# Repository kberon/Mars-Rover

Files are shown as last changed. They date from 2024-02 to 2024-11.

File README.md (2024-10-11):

Repo for parts for the MIL Rover

Old Rover CAD Screenshot

contact: adammcaleer@ufl.edu

## Project Architecture
Iamge overview

### Finished tasks
Firmware has somewhat shifted away from a build system using wiringPI as a HAL for c++ - have moved towards a build system for assembly and C for performance. <br>
The basics of the drivers for PWM are done under the c_drivers directory, and drivers for an IMU and BME280 are available under the main branch now.<br>
We have now also added configurations for sonar in the form of a kernel interrupt - this being done once again in hopes of better performance<br>
<br>
Our high level software team has finished configuring ROS for our external computer nodes, and have dived into the details of ROS through toturials.<br>
<br>
Additionally, the team has dived into the battery monitor board design, and details of the future voltage dividing procedure.<br>
<br>
The team has also spent a great deal of time researching and buying parts. Included in the documentation directory are details on that procedure, especailly for the motor selection<br>
<br>
We encourage you to explore the repo and read the subdirectory README's and the different available documentation

## Bugs
Firmware bugs are as follows: PWM through DMA drivers needs to become a persistant object to capture memory leaks - otherwise causes issues when run multiple times<br>
Our sonar modules work independently, but need some kind of daisychaning or internal delays to prevent interference with one another.

## Set up to run:
1. Load the gpio_interface module for PWM
```
cd /Mars-Rover/firmware/kernel_modules/
sudo insmod gpio_interface.ko
```

## Installation:
1. Clone our repo
```
git clone https://github.com/kberon/Mars-Rover.git
```
2. Instantiate the kernel modules on start up
```
sudo nano /etc/systemd/system/load_custom_modules.service
```
In that file write:
```
[Unit]
Description=Load Custom Sonar Kernel Modules
After=network.target

[Service]
Type=oneshot
ExecStart=/sbin/insmod /home/raspberry/Mars-Rover/firmware/sonar_1/sonar_1.ko
ExecStart=/sbin/insmod /home/raspberry/Mars-Rover/firmware/sonar_2/sonar_2.ko
ExecStart=/sbin/insmod /home/raspberry/Mars-Rover/firmware/sonar_3/sonar_3.ko
RemainAfterExit=yes

[Install]
WantedBy=multi-user.target
```
Save the file and run the following commands:
```
sudo systemctl daemon-reload
sudo systemctl enable load_custom_modules.service
```

3. For the sensor setup, we will need to install the WiringPi library
```
cd Mars-Rover/firmware/drivers
git clone https://github.com/WiringPi/WiringPi.git
cd WiringPi
./build debian
sudo dpkg -i debian-template/wiringpi_3.10_arm64.deb
```
4. Docker setup
Get the install script:
```
curl -fsSL https://get.docker.com -o get-docker.sh
chmod +x get-docker.sh
```
Remove an existing docker installations with:
```
sudo apt-get purge docker-ce docker-ce-cli containerd.io -y
```
Run the script:
```
./get-docker.sh
```
Fix permissions:
```
sudo usermod -aG docker pi
sudo systemctl unmask docker
sudo chmod 666 /var/run/docker.sock
```
Install docker-compose:
```
pip3 -v install docker-compose
```
Start and reboot Docker:
```
sudo systemctl start docker
sudo init 6
```   
6. To run our camera + sensors executable:
```
sudo apt-get install libgtk-3-dev
sudo apt-get install libopencv-dev
sudo apt install python3-opencv
```

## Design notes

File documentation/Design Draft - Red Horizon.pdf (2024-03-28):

### Design Revision CEN3907C: Senior Design for Computer Engineering

Red Horizon Team
Kayleigh Beron, Andrea Chacon, Morgan Cobb, Kayla Dunnuck, Quintin Lopez-Scarim Machine Intelligence Lab - University of Florida

Table of Contents

Introduction
The Red Horizon project aims to develop a prototype of a Mars rover, integrating advanced features to enhance its autonomy and functionality.

Purpose/Need

The purpose of the Red Horizon project lies in providing an educational and research platform for exploring the capabilities of machine intelligence in autonomous robotic systems. This replica serves as a valuable tool for students, researchers, and educators at the Machine Intelligence Lab to study and experiment with autonomous navigation, object detection, and sensor integration. By simulating the functionalities of a Mars rover, the project fulfills the need for practical hands-on experience in developing and deploying intelligent robotic systems.

Red Horizon will be used by the Machine Intelligence Lab to show off the kinds of autonomous projects students of all ages could work on if they choose to pursue STEM and join MIL. However, there are many possible applications as well, as its mechanical chassis design and motor system allow for movement across all kinds of terrains. It’s strong ability to go over things in all kinds of terrain, make it possible to be used in emergency situations, where it could use the camera to detect victims in areas of natural disasters or cramped spaces where it would be too dangerous to send a person without confirmation of victims.

Domain & Prior Art

The Red Horizon project operates within the field of autonomous robotics and control systems. While there have been significant achievements in this domain, including successful Mars rover missions conducted by various countries, our project aims to recreate this to not only help Machine Intelligence Lab bring a stronger attraction to STEM education with something of great historical significance, but to create something that could be applied in emergencies.

Some prior art would be the original Mars Rover that we would be imitating from, as the wheels and mechanical system are nearly identical. As for educational prior art, Makeblock creates “mBots” that are robots that can easily be built and programmed by young teens, to get introduced to the basics of robotics and allow young engineers to both learn and play with the robot they’ve created. The FIRST Competition is also a robotics competition aimed at middle schoolers and high schoolers of different levels to create a robot with autonomous and telemetry modes with computer vision, that allow young kids to learn about the basics of robotics and gain interest.

Differentiation

As for how Red Horizon will be different, Red Horizon will be more complex than those educational tools like FIRST and mBots, as it is a project that wouldn’t be built by the young kids it is aiming to inspire as it would be too difficult for their level. It is a chance for those kids who are working in FIRST Robotics, to see a more complex project and the real world applications of what they could be working on. This is a project we could bring to local schools with FIRST robotics teams and allow them to play with it while seeing how they can apply robotics outside of a high-school competition.

Impact & Risk Assessment

The impact of the Red Horizon project extends primarily to the educational and research domains within the university community. By providing a hands-on learning experience, the project enhances students' understanding of machine intelligence, robotics, and computer engineering.
The project also raises ethical and privacy concerns, particularly regarding the use of onboard cameras for object detection and navigation. The potential for unintended surveillance or privacy breaches requires careful consideration and implementation of privacy safeguards. As for how we will address this, we will ensure that the robot cannot leave MIL room by trying to make a docking station for it, and ensure the camera is at an angle it can only see directly in-front from a low height. The controllers for it will be kept by Dr. Schwartz as well.

Drawbacks and Limitations

While creating a Mars rover replica like Red Horizon for educational purposes is exciting, it comes with several drawbacks and limitations. Firstly, reliance on computer vision for navigation may be prone to errors in identifying colors and shapes accurately, especially in challenging environments. Additionally, the rover's autonomy may lead to unpredictable behavior, potentially causing collisions or getting stuck in obstacles. Moreover, replicating the complex terrain and environmental conditions of Mars accurately can be difficult, limiting the realism and educational value of the experience. Overall however, these limitations shouldn’t be too large to affect the educational experience.

Statement of Work

By the pre-alpha build (03/27) the Red Horizon team plans to have drivers for the Motors and the controller, along with our high level ROS (Robot Operating System) environment. For the drivers we plan to use C++,C, and potentially some assembly for speed and efficiency. C++ and C will be the default for most drivers, and assembly will be used for some reach goal by utilizing some cutting edge communication protocols. For the specific communication protocols we plan to use for each peripheral please see either the tables below, or the diagram included in the systems section. We will use Cmake as our build system since it meshes well with C++, C, assembly, and ROS. The motor board and kill board will be completed and most parts should be ordered and will continue until the end of the alpha build. We also hope to order sonar kits, and to have a better foundational understanding of the current mechanical state of the Red Horizon.

By the completion of our prototype (04/16) development, we hope to have drivers for the gyroscope, camera, and interfacing with our external computer. Once again, we will be utilizing C++,C, and assembly for that, along with Cmake as our build system. The voltage divider board and battery monitor board will be completed and tested to ensure functionality. Some of our secondary features that we hope to get done include drivers for an accelerometer, and patching up any mechanical issues.

As for our alpha build/demo (08/27) we plan to have attached sonar with drivers in C and C++ using Cmake, and hope to utilize daisy-chaining to increase their accuracy. With those sonar attachments come more information that we can use to increase autonomy, which we hope to have at a sufficient level to roam on its own at this point without destroying itself. . Bluetooth and wifi will also be connected to the controllers to the kill board and raspberry pi. LCD output will be created and tested to ensure data from the screen outputs all current data correctly.

Pre-Alpha build

Core features | Done by: | Secondary features | Timeline (Starting March 11th)
Controller Drivers (wifi) | Quintin and Andrea | Order sonar kits/start researching how to daisy chain them | Week 2
Motor/DAC Drivers | Quintin and Andrea | | Week 3
Configure ROS | Morgan | | Week 1-2
Begin teleop code | Morgan and Kayla | | Week 2

Determine the current mechanical state of Red Horizon | Quintin | Week 1
Motor and Kill Board | Kayleigh and Kayla | Weeks 1-3
Initialize Raspberry Pi | Andrea | Weeks 1-3

Prototype

Core features | Done by: | Secondary features | Timeline (Week 4 starting 04/01/2024)
Motors attached with minimal functionality | Everyone | Accelerometer drivers | Weeks 4-6
Gyroscope drivers (I2C) | Quintin | Mechanical fixes | Week 4-5
UI for data/connectivity with computer | Morgan and Kayla | | Week 4
Begin high level data analysis (basic autonomy) | Morgan and Kayla | | Week 5-6
Add camera with base drivers (USB) | Andrea | | Week 6
Configure LCD to Raspberry Pi (SPI) | Andrea | | Week 4-5
Configure remote controller (WIFI) | Andrea and Kayleigh | | Week 5-6
Voltage Divider and Battery Monitor Board | Kayleigh and Kayla | | Week 4-6

Alpha build/demo

Core features | Done by: | Secondary features | Timeline (Continuing on starting 08/12/2024 with some work done over summer)
Attach functioning sonar | Quintin and Andrea | Path mapping with an accelerometer | Week 7-8
Basic autonomy through high level interactions finished | Quintin and Andrea | Mechanical fixes | Week 9-10
Finish part ordering | Kayleigh | | Week 7
Start testing and integration | Everyone | | Week 7-10

Deliverable Artifacts

We intend to deliver the software for the control, as well as drivers/libraries created for the firmware in a github repository. Documentation in the form of jupyter notebooks for these drivers will be provided. Additionally, we will deliver the PCB’s used for the kill board, voltage divider board, motors board, and battery monitor board with their schematics. The final product will be all of these features combined onto the working rover, and delivered to the faculty supervisor, to be used for future research lab demos.

As for how this will be maintained for long-term use there are several plans. The robot will stay in the Machine Intelligence Lab, and the controllers will be kept by Dr. Schwartz. We will provide the CUI to Dr. Schwartz, and keep it on one of the computers in the MIL lab. On one of the computers in the MIL lab, students should just receive the controllers by Dr. Schwartz, run the .exe file on the MIL computer to open the CUI, and once the controllers are connected and the CUI is booted establishing connection to the rover, students should be free to use the rover around the room as pleased. This software will also be available on one of the MIL laptops that can be used at outreach events with local schools for educational purposes, and documentation will be provided on how to use and how to fix some possible issues. Lastly, we will provide a final paper that describes how it works that can be studied by any MIL member.

Mockups
Interfaces

The main interface of this project would be the Bluetooth Logitech Controllers and the LCD Screen. The main inputs from humans come from the kill button (a large physical button on the exterior of the robot to emergency kill), as well as the bluetooth controllers that would change the rover from autonomous to teleop mode (driving by human control) by moving a joystick, and reset it based on a button. We could possibly also try a phone app, not sure if we will implement that yet. The LCD screen would display the status of everything (kill/not kill mode, teleop or autonomous mode, temperature, humidity, altitude, orientation, and if detecting anything on the sensors, all based on the different sensors).
Below is a possible LCD Screen output:

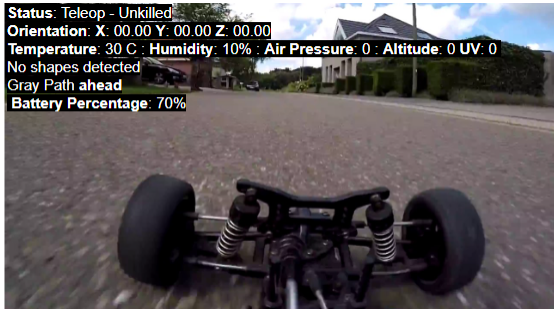
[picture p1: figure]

Figure 1: Potential LCD Screen output Below is a possible remote controller mapping. The soil test is specifically for activating the soil test state that would push a servo stick into the dirt, and output the results from it into the LCD display.

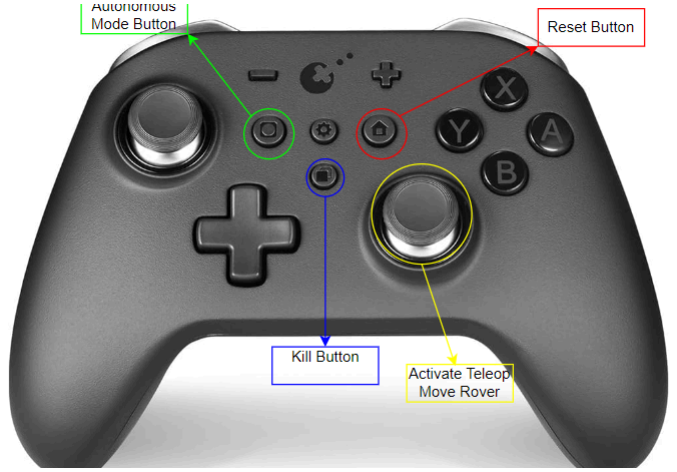
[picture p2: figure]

Figure 2: Remote Controller Map

Systems

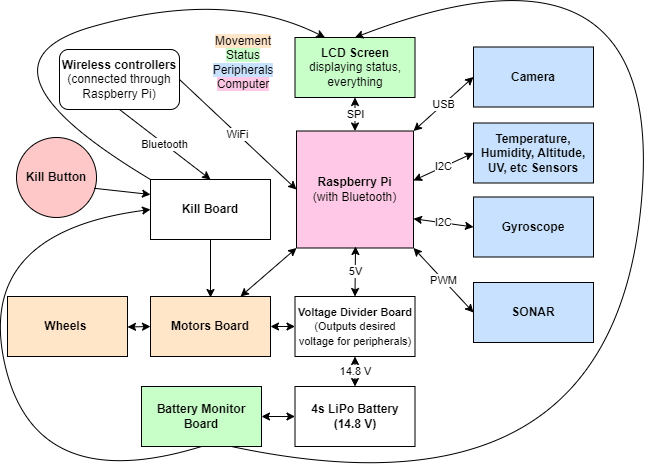
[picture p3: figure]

Above is the general hardware system diagram for our project. Below is the block diagram for the high-level software (computer vision) algorithm. Our main computer will be a Raspberry Pi with Bluetooth functionality that would connect via Bluetooth to the Kill Board (kills all motors/servos when necessary).

We would have a motor system with different motors for each wheel, (possibly mecanum wheels), an arm system involving a servo that just sticks a soil quality sensor into the dirt, and output displayed on the LCD. We would also have a camera connected to the computer searching for shapes and colors (e.g: red circle detected in the distance). Lastly there should be a status system for killed, unkilled, autonomous, teleop, etc.

Networking

There are several necessary communication protocols to fully implement our rover. We would use Serial Peripheral Interface (SPI) communication from our Pi to the screen, to be able to display our sensor and critical information quickly. Additionally, the sensors will use Inter-Integrated Circuits (I2C) or SPI - depending on how critical the data transfers are, as well as the physical location of the hardware components. Additionally, we will use Pulse Width Modulation (PWM) to communicate with the sonar sensors, encoding analog signals into digital signals.

In order to communicate with our Pi from our controller, we will use a CUI that will send instructions to the Pi via Wifi for high data transfer, wide coverage range, and flexibility. We will also use bluetooth or wifi to communicate with the kill board.

Storyboards

The LCD, which is the biggest output, will just look like this most of the time, with the values not in bold, changing every millisecond.

Storyboard example:

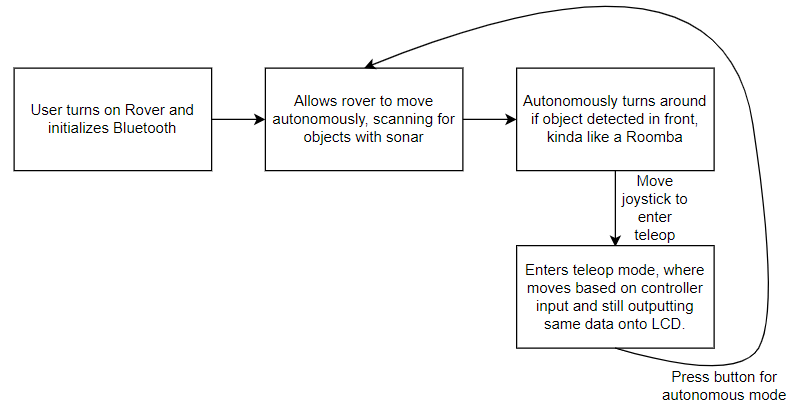
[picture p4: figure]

Draft Schematics

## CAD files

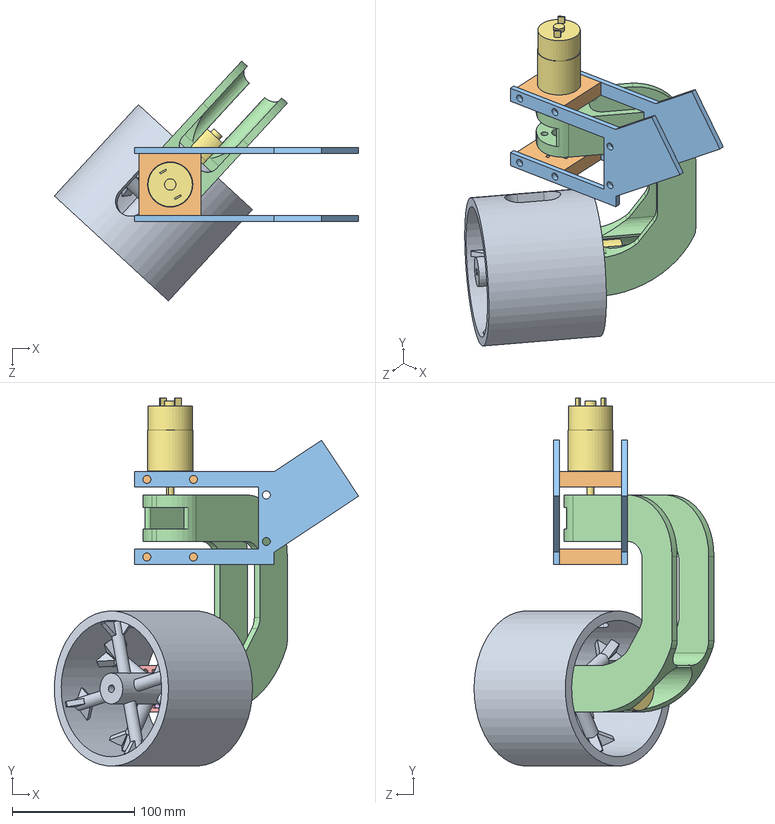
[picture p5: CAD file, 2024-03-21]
CAD Parts/New CAD/Wheel_Assem.SLDASM
249.2 x 301.4 x 196.4 mm
DC Motor x 2
Motor Mount
Wheel Mount
Wheel Join Whole
frame_standin x 2
Frame_Join_A x 2
Wheel Interior

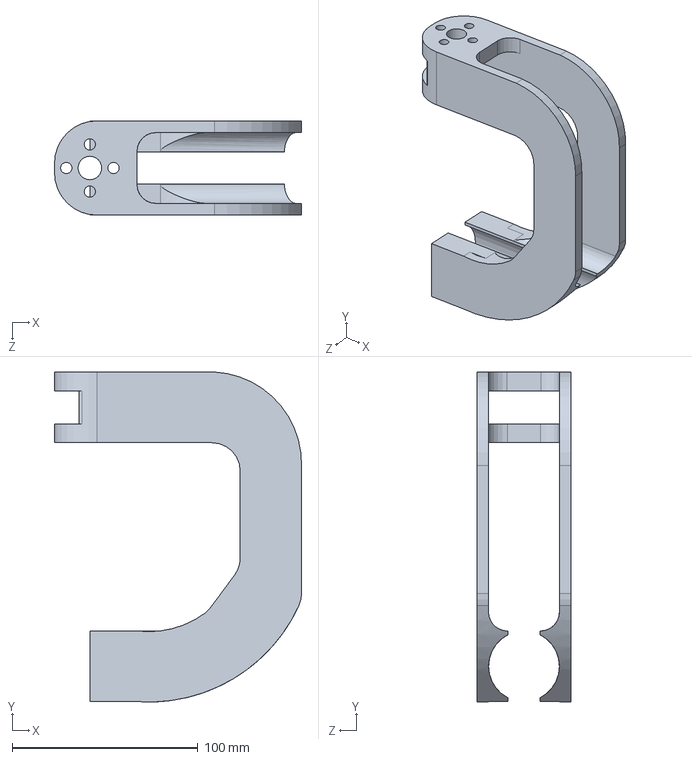
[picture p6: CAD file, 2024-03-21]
CAD Parts/New CAD/Wheel Join Whole.SLDPRT
133.1 x 177.8 x 50.8 mm

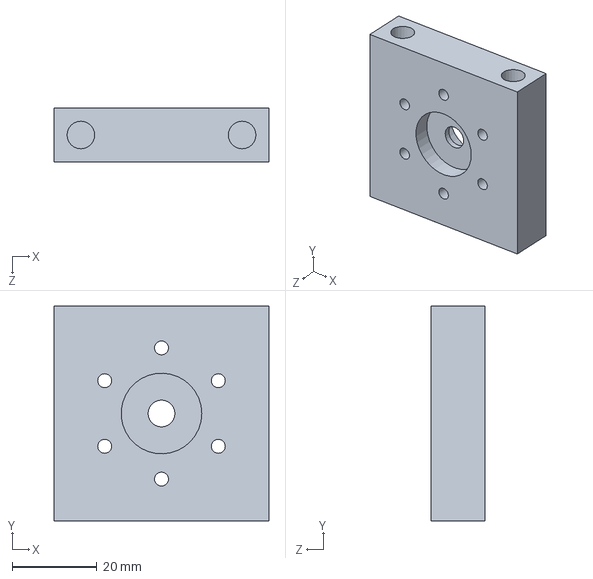
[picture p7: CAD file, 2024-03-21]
CAD Parts/New CAD/Frame_Join_A.SLDPRT
50.8 x 50.8 x 12.7 mm

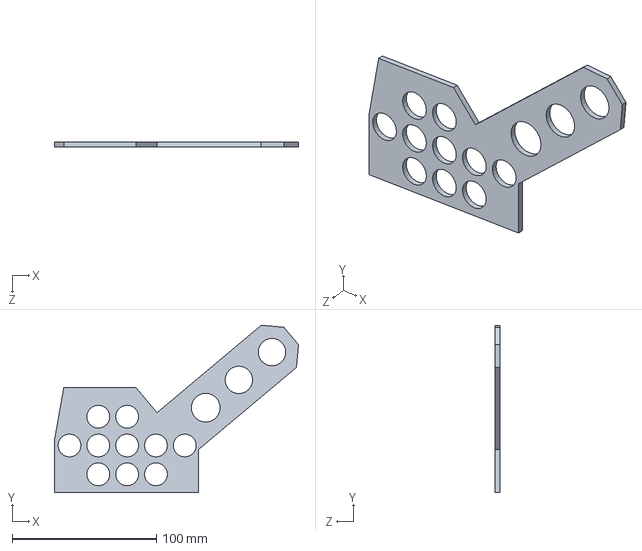
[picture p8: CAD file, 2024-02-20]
Frame_A.SLDPRT
169.3 x 116.2 x 3.17 mm

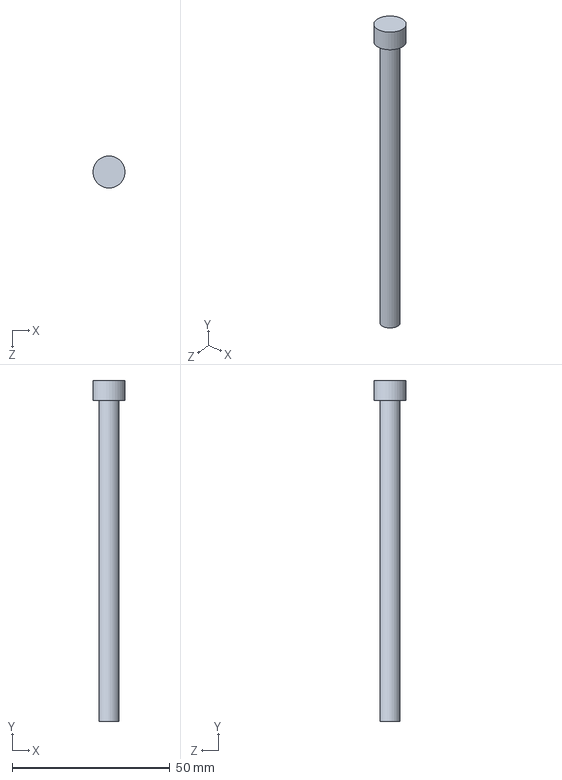
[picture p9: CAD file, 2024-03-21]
CAD Parts/Fixed CAD/3_in_pin.SLDPRT
10.1 x 108.0 x 10.2 mm

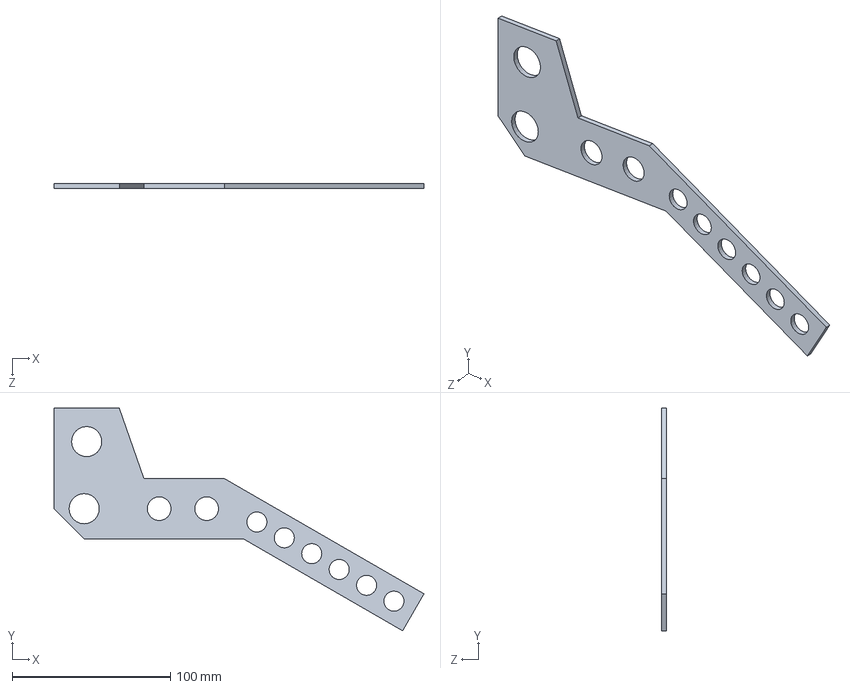
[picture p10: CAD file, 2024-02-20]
Frame_B.SLDPRT
233.8 x 140.7 x 3.17 mm

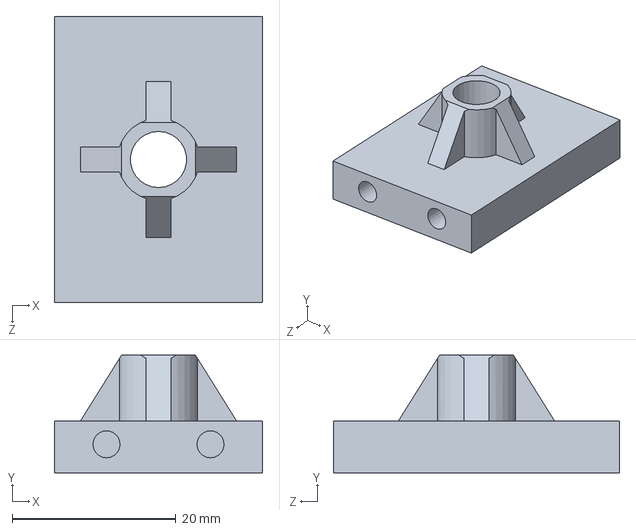
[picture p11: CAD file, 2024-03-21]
CAD Parts/Fixed CAD/Wheel_mount.SLDPRT
25.4 x 14.3 x 34.9 mm

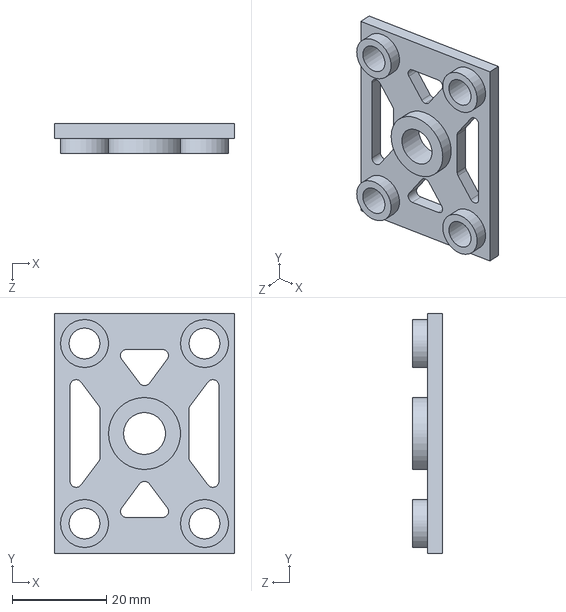
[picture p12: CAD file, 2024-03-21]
CAD Parts/New CAD/Wheel Mount.SLDPRT
38.1 x 50.8 x 6.35 mm

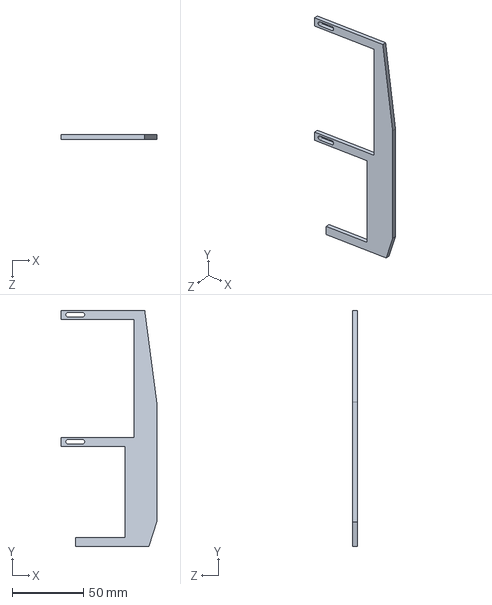
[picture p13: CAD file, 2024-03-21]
CAD Parts/Fixed CAD/Wheel_Bracket.SLDPRT
66.8 x 165.1 x 3.17 mm

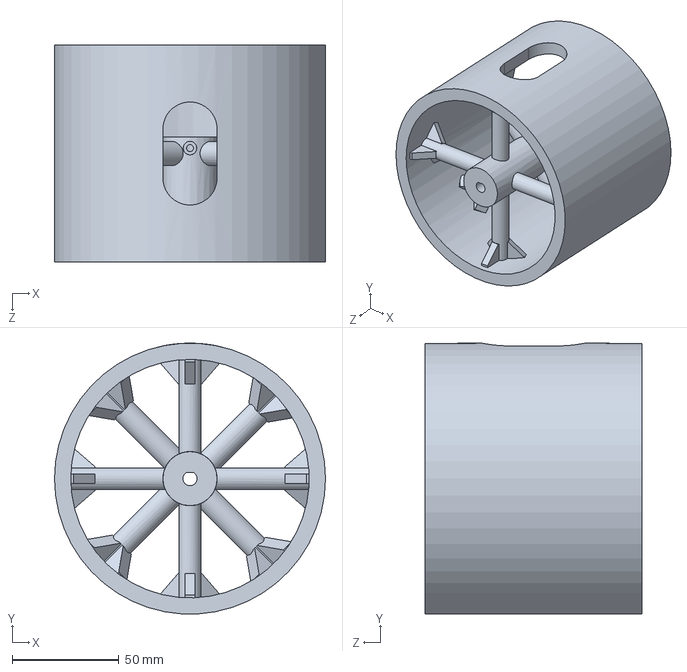
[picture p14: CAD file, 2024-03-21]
CAD Parts/New CAD/Wheel Interior.SLDPRT
127.0 x 126.9 x 101.6 mm

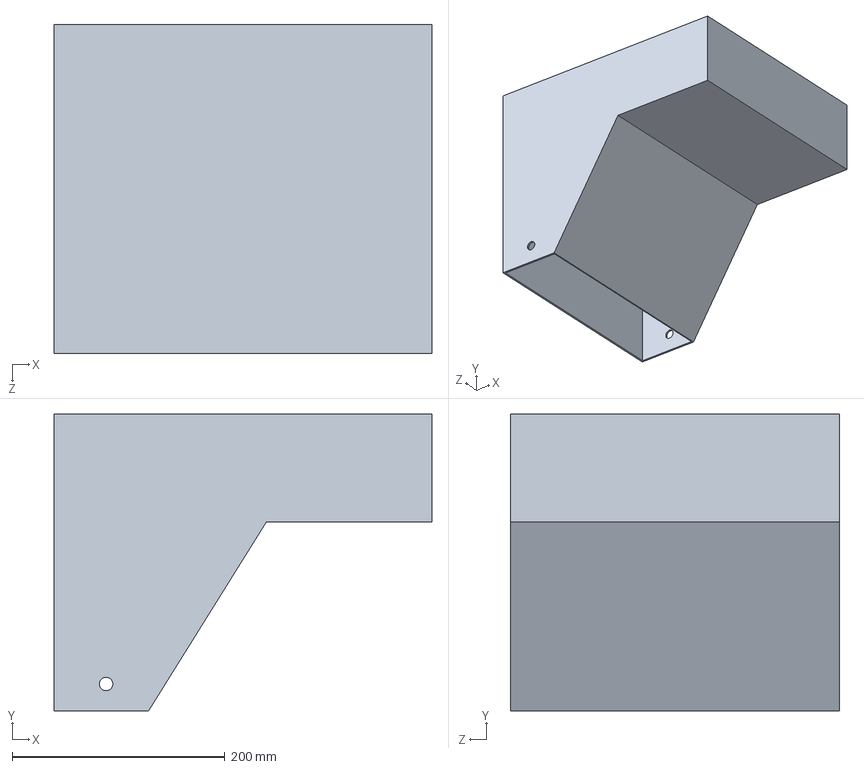
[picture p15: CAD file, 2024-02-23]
CAD Parts/Fixed CAD/Chassis.SLDPRT
355.6 x 279.4 x 309.9 mm

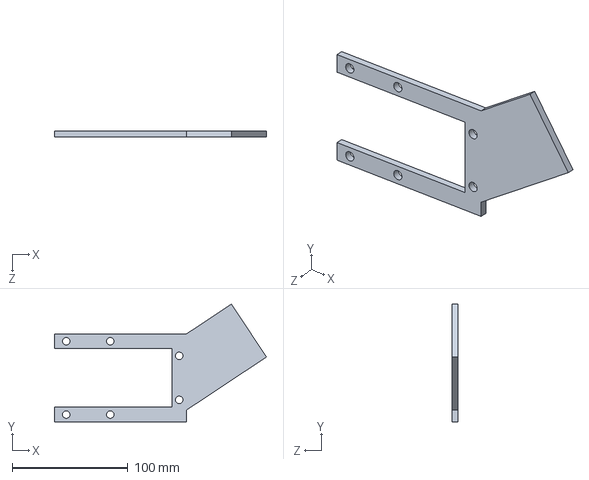
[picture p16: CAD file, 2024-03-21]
CAD Parts/New CAD/frame_standin.SLDPRT
183.5 x 102.0 x 4.76 mm

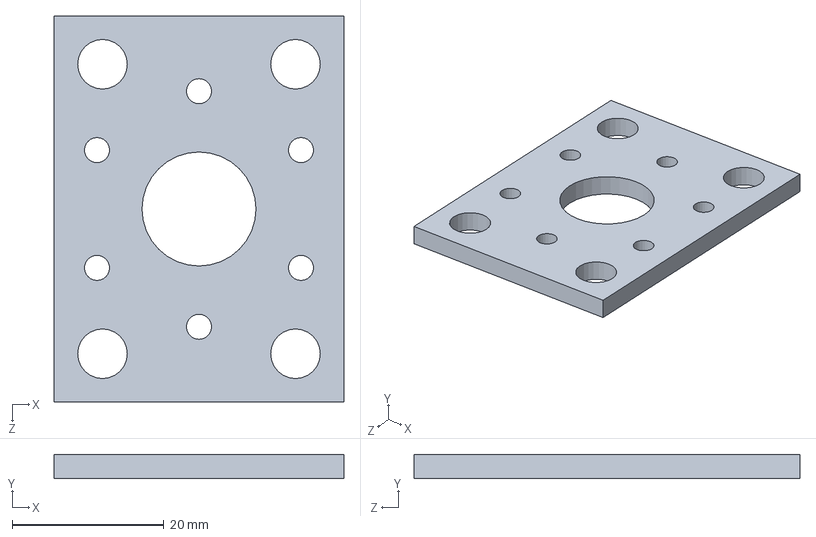
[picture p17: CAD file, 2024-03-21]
CAD Parts/New CAD/Motor Mount.SLDPRT
38.1 x 3.17 x 50.8 mm

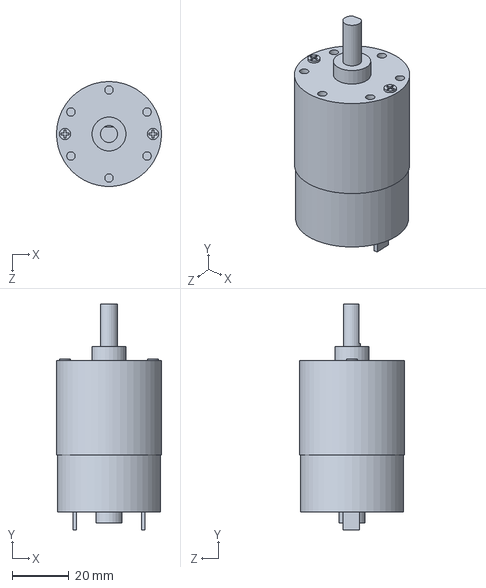
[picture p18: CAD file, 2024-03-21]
CAD Parts/New CAD/DC Motor.SLDPRT
37.0 x 79.6 x 37.0 mm

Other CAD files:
CAD Parts/Fixed CAD/Frame_A.SLDPRT
CAD Parts/Fixed CAD/Frame_B.SLDPRT
CAD Parts/Fixed CAD/Frame_C.SLDPRT
CAD Parts/Fixed CAD/0_5_in_shaft.SLDPRT
CAD Parts/Fixed CAD/0_75_in_shaft.SLDPRT
CAD Parts/Fixed CAD/Swerve_mount.SLDPRT
CAD Parts/Fixed CAD/Wheel.SLDPRT
CAD Parts/New CAD/Frame_Join_B.SLDPRT
CAD Parts/New CAD/Shaft Coupler.SLDPRT
CAD Parts/Old CAD/Old_Assembly.SLDASM

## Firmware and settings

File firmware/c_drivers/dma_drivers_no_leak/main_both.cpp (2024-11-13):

/******************** INCLUDES ********************/
#include "gpio_drivers.h"
#include "dma_drivers.h"
#include <iostream>
#include <fstream>
#include <string>
#include <linux/input.h>
#include <fcntl.h>
#include <unistd.h>
/******************** INCLUDES ********************/
/************************* DEFINES *************************/
#define SONAR1 16
#define SONAR2 20
#define SONAR3 21

#define MOTOR1_EN 5
#define MOTOR2_EN 6
#define MOTOR3_EN 13
#define MOTOR4_EN 19
#define MOTOR5_EN 26
#define MOTOR6_EN 12

// had to swap forward and backward
// #define L_IN1 8
// #define L_IN2 7
// #define R_IN1 14
// #define R_IN2 15

#define L_IN1 7
#define L_IN2 8
#define R_IN1 15
#define R_IN2 14

#define device_path "/dev/input/event4" // change as needed
// const char* device_path = "/dev/input/event10";
// ls /dev/input/event*
/************************* DEFINES *************************/

// buttons: right middle : switch modes, left middle: kill

/******************** GLOBAL VARIABLES ********************/
bool mode = true; // 0 = autonomous, 1 = teleop
dma_handler dma_object = dma_handler(50, 250, 0, 26);

int current_dir = 0; // 0 for stop, 1 for forward, 2 for right, 3 for back, 4 for left

int fd_controller;
struct input_event ev;

const char* sonarFiles[] = {
    "/sys/kernel/sonar_1_time/time_diff",
    "/sys/kernel/sonar_2_time/time_diff",
    "/sys/kernel/sonar_3_time/time_diff"
};

long long sonarValues[] = {-1, -1, -1};

/******************** GLOBAL VARIABLES ********************/

/******************** FUNCTIONS ********************/
void move_backward(uint8_t power, dma_handler &dma_object, gpio_drivers &gpio)
{

    gpio.set_high(L_IN1);
    gpio.set_low(L_IN2);
    gpio.set_low(R_IN1);
    gpio.set_high(R_IN2);

    dma_object.modify_blocks(power, 250, MOTOR1_EN);
    dma_object.modify_blocks(power, 250, MOTOR2_EN);
    dma_object.modify_blocks(power, 250, MOTOR3_EN);
    dma_object.modify_blocks(power, 250, MOTOR4_EN);
    dma_object.modify_blocks(power, 250, MOTOR5_EN);
    dma_object.modify_blocks(power, 250, MOTOR6_EN);
}

void move_forward(uint8_t power, dma_handler &dma_object, gpio_drivers &gpio)
{
    gpio.set_low(L_IN1);
    gpio.set_high(L_IN2);
    gpio.set_high(R_IN1);
    gpio.set_low(R_IN2);

    dma_object.modify_blocks(power, 250, MOTOR1_EN);
    dma_object.modify_blocks(power, 250, MOTOR2_EN);
    dma_object.modify_blocks(power, 250, MOTOR3_EN);
    dma_object.modify_blocks(power, 250, MOTOR4_EN);
    dma_object.modify_blocks(power, 250, MOTOR5_EN);
    dma_object.modify_blocks(power, 250, MOTOR6_EN);
}

void turn_left(uint8_t power, dma_handler &dma_object, gpio_drivers &gpio)
{
    gpio.set_high(L_IN1);
    gpio.set_low(L_IN2);
    gpio.set_high(R_IN1);
    gpio.set_low(R_IN2);

    dma_object.modify_blocks(power, 250, MOTOR1_EN);
    dma_object.modify_blocks(power, 250, MOTOR2_EN);
    dma_object.modify_blocks(power, 250, MOTOR3_EN);
    dma_object.modify_blocks(power, 250, MOTOR4_EN);
    dma_object.modify_blocks(power, 250, MOTOR5_EN);
    dma_object.modify_blocks(power, 250, MOTOR6_EN);
}

void turn_right(uint8_t power, dma_handler &dma_object, gpio_drivers &gpio)
{
    gpio.set_low(L_IN1);
    gpio.set_high(L_IN2);
    gpio.set_low(R_IN1);
    gpio.set_high(R_IN2);

    dma_object.modify_blocks(power, 250, MOTOR1_EN);
    dma_object.modify_blocks(power, 250, MOTOR2_EN);
    dma_object.modify_blocks(power, 250, MOTOR3_EN);
    dma_object.modify_blocks(power, 250, MOTOR4_EN);
    dma_object.modify_blocks(power, 250, MOTOR5_EN);
    dma_object.modify_blocks(power, 250, MOTOR6_EN);
}

/*
void read_sonar_1(long long &time_me)
{
    FILE *file;
    file = fopen("/sys/kernel/sonar_1_time/time_diff", "r");
    long long time = -1;
    if (file == NULL)
    {
        perror("Error opening file");
        time_me = -1;
        return;
    }
    if (fscanf(file, "%lld", &time) != 1)
    {
        printf("Error reading number from file\n");
        time_me = -1;
    }
    else
    {
        // printf("sonar 1 pre-conversion: %lld\n" , time);
        time_me = time / 58000;
        printf("sonar_1 Read number: %lld\n", time_me);
    }
    fclose(file);
}

void read_sonar_2(long long &time_me)
{
    FILE *file;
    long long time = -1;
    file = fopen("/sys/kernel/sonar_2_time/time_diff", "r");
    if (file == NULL)
    {
        perror("Error opening file");
        time_me = -1;
        return;
    }
    if (fscanf(file, "%lld", &time) != 1)
    {
        printf("Error reading number from file\n");
        time_me = -1;
    }
    else
    {
        time_me = time / 58000;
        printf("sonar_2 Read number: %lld\n", time_me);
    }
    fclose(file);
}

void read_sonar_3(long long &time_me)
{
    FILE *file;
    file = fopen("/sys/kernel/sonar_3_time/time_diff", "r");
    long long time = -1;
    if (file == NULL)
    {
        perror("Error opening file");
        time_me = -1;
        return;
    }
    if (fscanf(file, "%lld", &time) != 1)
    {
        printf("Error reading number from file\n");
        time_me = -1;
    }
    else
    {
        time_me = time / 58000;
        printf("sonar_3 Read number: %lld\n", time_me);
    }
    fclose(file);
}
*/

void read_sonar(int sonarNumber, long long &time_me, const char* fileName)
{
    FILE *file;
    file = fopen(fileName, "r");
    long long time = -1;
    if (file == NULL)
    {
        perror("Error opening file");
        time_me = -1;
        return;
    }
    if (fscanf(file, "%lld", &time) != 1)
    {
        printf("Error reading number from file\n");
        time_me = -1;
    }
    else
    {
        time_me = time / 58000;
        printf("%d Read: %lld\n", sonarNumber, time_me);
    }
    fclose(file);
}

void prompt_sonar(gpio_drivers &gpio)
{
    gpio.set_high(SONAR1);
    sleep(0.01);
    gpio.set_low(SONAR1);
    sleep(0.80);
    gpio.set_high(SONAR2);
    sleep(0.01);
    gpio.set_low(SONAR2);
    sleep(0.80);
    gpio.set_high(SONAR3);
    sleep(0.01);
    gpio.set_low(SONAR3);
    sleep(.4);
    return;
}

void init_motors_and_sonar(gpio_drivers &gpio)
{
    dma_object.turn_off();

    gpio.set_output(MOTOR1_EN);
    gpio.set_output(MOTOR2_EN);
    gpio.set_output(MOTOR3_EN);
    gpio.set_output(MOTOR4_EN);
    gpio.set_output(MOTOR5_EN);
    gpio.set_output(MOTOR6_EN);

    gpio.set_output(L_IN1);
    gpio.set_output(L_IN2);
    gpio.set_output(R_IN1);
    gpio.set_output(R_IN2);

    // setting up sonar triggers
    gpio.set_output(SONAR1);
    gpio.set_output(SONAR2);
    gpio.set_output(SONAR3);
}

int init_controller()
{
    // Controller input setup
    fd_controller = open(device_path, O_RDONLY);
    if (fd_controller == -1)
    {
        std::cerr << "Failed to open input device: " << device_path << std::endl;
        return 1;
    }
    return 0;
}
/******************** FUNCTIONS ********************/

/******************** MAIN ********************/
int main()
{
    gpio_drivers gpio = gpio_drivers();
    init_motors_and_sonar(gpio);
    init_controller();

    while (true)
    {
        //PRINT MODE
        if (mode == true)
        {
            std::cout << " NOW RUNNING: TELEOP MODE" << std::endl;
        }
        else
        {
            std::cout << " NOW RUNNING: AUTONOMOUS MODE" << std::endl;
        }

        //TELEOP MODE
        while (mode == true)
        {
            fcntl(fd_controller, F_SETFL, 0);
            uint8_t power = 40; // 100: Default power level for motors
            //cout << "IN TELOP MODE: " << mode << endl;

            //READ CONTROLLER
            ssize_t bytes = read(fd_controller, &ev, sizeof(ev));
            if (bytes < (ssize_t)sizeof(ev))
            {
                std::cerr << "Error reading input event" << std::endl;
                break;
            }

            if (ev.type == EV_KEY)
            {
                if (ev.value == 1)
                { // Key pressed
                    switch (ev.code)
                    {
                    case BTN_Y: // Y button: Move forward
                        if (current_dir != 1)
                        { // if not currently moving foward
                            dma_object.turn_off();
                            sleep(1);
                            current_dir = 1;
                        }
                        move_forward(power, dma_object, gpio);
                        std::cout << "Button Y pressed: Moving forward" << std::endl;
                        break;
                    case BTN_A: // A button: Move backward
                        if (current_dir != 3)
                        { // if not currently moving backwards
                            dma_object.turn_off();
                            sleep(1);
                            current_dir = 3;
                        }
                        move_backward(power, dma_object, gpio);
                        std::cout << "Button A pressed: Moving backward" << std::endl;
                        break;
                    case BTN_X: // X button: Turn left
                        if (current_dir != 4)
                        { // if not currently moving left
                            dma_object.turn_off();
                            sleep(1);
                            current_dir = 4;
                        }
                        turn_left(power, dma_object, gpio);
                        std::cout << "Button X pressed: Moving left" << std::endl;
                        break;
                    case BTN_B: // B button: Turn right
                        if (current_dir != 2)
                        { // if not currently moving right
                            dma_object.turn_off();
                            sleep(1);
                            current_dir = 2;
                        }
                        turn_right(power, dma_object, gpio);
                        std::cout << "Button B pressed: Moving right" << std::endl;
                        break;
                    case BTN_START:
                        dma_object.turn_off();
                        mode = false;
                        current_dir = 0;
                        std::cout << "Changing to autonomous mode: " << mode << std::endl;
                        sleep(1);
                        break;
                    case BTN_SELECT:
                        dma_object.turn_off();
                        std::cout << "KILLED" << std::endl;
                        return 0;
                    }
                }
                else if (ev.value == 0)
                { // Key released
                    dma_object.turn_off();
                }
            }
            //cout << "END OF TELEOP LOOP: " << mode << endl;
        }

        //PRINT MODE
        if (mode == true)
        {
            std::cout << " NOW RUNNING: TELEOP MODE" << std::endl;
        }
        else
        {
            std::cout << " NOW RUNNING: AUTONOMOUS MODE" << std::endl;
        }

        //SETUP FOR AUTONOMOUS
        prompt_sonar(gpio);
        //long long sonar_1_value = -1;
        for(int i = 0; i < 3; i++){
            sonarValues[i] = -1;
        }
        move_forward(40, dma_object, gpio);
        fcntl(fd_controller, F_SETFL, O_NONBLOCK);

        //AUTONOMOUS MODE
        while (mode == false)
        {
            //cout << "IN AUTONOMOUS MODE" << endl;
            // READ CONTROLLER
            for (int i = 0; i < 10; i++)
            { // Check multiple times
                ssize_t bytes = read(fd_controller, &ev, sizeof(ev));
                if (bytes == sizeof(ev))
                {
                    //std::cout << "button read: " << ev.code << std::endl;
                    if (ev.type == EV_KEY && ev.value == 1)
                    {
                        switch (ev.code)
                        {
                        case BTN_START:
                            dma_object.turn_off();
                            mode = true;
                            fcntl(fd_controller, F_SETFL, 0);
                            std::cout << "Changing to teleop mode" << std::endl;
                            sleep(1);
                            break;
                        case BTN_SELECT:
                            dma_object.turn_off();
                            std::cout << "KILLED" << std::endl;
                            return 0;
                        }
                    }
                }
                else if (bytes == -1 && errno != EAGAIN)
                {
                    std::cerr << "Error reading from controller" << std::endl;
                    break;
                }
            }

            // std::cout << "OUT OF READING IN AUTONOMOUS MODE " << std::endl;
            // BREAK EARLY IF MODE CHANGED
            if (mode == true)
            {
                break;
            }

            // IF NOT SWITCH OR KILL, CONTINUTE AUTONOMOUS MODE (PROMPT SONAR, EVAL)
            //SUGGESTED APPROACH, IDK IF ITLL WORK PLEASE CHECK
            prompt_sonar(gpio);
            for(int i = 0; i < 3; i++){
                read_sonar((i + 1), sonarValues[i], sonarFiles[i]);
            }

            //prompt_sonar(gpio);
            //read_sonar_1(sonar_1_value);
            //prompt_sonar(gpio);
            //read_sonar_1(sonar_1_value);
            //sonar_1_value = 0;
            //move_forward(40, dma_object);

            // check if too close to something, turn right
            if (sonarValues[0] < 50 || sonarValues[1] < 50 || sonarValues[2] < 50)
            {
                dma_object.turn_off();
                sleep(1);
                turn_right(100, dma_object, gpio);
                sleep(2);
                dma_object.turn_off();
                move_forward(40, dma_object, gpio);
            }
            usleep(10000);
        }
    }

    close(fd_controller);
    return 0;
}
/******************** MAIN ********************/

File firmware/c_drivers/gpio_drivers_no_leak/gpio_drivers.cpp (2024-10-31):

#define gpiomem "/dev/gpiomem"
#define GPIOSET0 0x1c / 4
#define GPCLR0 0x28 / 4

#include <cstdint>
#include <sys/mman.h>
#include <fcntl.h>
#include <sys/types.h>
#include <sys/stat.h>
#include <unistd.h>

#include <iostream>
#include <bitset> // Include this for std::bitset
#include "gpio_drivers.h"

/*void print_32(uint32_t to_print)
{
	std::cout << "\n"
			  << std::bitset<32>(to_print);
}*/


gpio_drivers::gpio_drivers()
{

char file_name[] = gpiomem;
int flags = 0x101002;
fd = openat(0, file_name, flags);
gpio_mem = reinterpret_cast<uint32_t *>(mmap(0, 4096, 3, 1, fd, 0));

}

void gpio_drivers::set_output(int selected_pin)
{

	int fsel = selected_pin / 10;
	int offset = selected_pin % 10;
	int desired_set = 1 << (offset * 3);

	uint32_t current = *(gpio_mem + fsel);
	uint32_t mask = ~(0b111 << (offset * 3));
	*(gpio_mem + fsel) = (current & mask) | desired_set;
}

void gpio_drivers::set_input(int selected_pin)
{

	int fsel = selected_pin / 10;
	int offset = selected_pin % 10;
	// int desired_set = 1<<(offset*3);

	uint32_t current = *(gpio_mem + fsel);
	uint32_t mask = ~(0b111 << (offset * 3));
	*(gpio_mem + fsel) = (current & mask); //|desired_set;
	return;
}

void gpio_drivers::set_high(int selected_pin)
{

	int set_clr_sel = selected_pin / 32;
	int set_clr_bit = selected_pin % 32;
	int mem_shift = GPIOSET0 + 4 * set_clr_sel;
	int mask = 0b1 << set_clr_bit;


	*(gpio_mem + mem_shift) = mask;
	return;
}

void gpio_drivers::set_low(int selected_pin)
{

	int set_clr_sel = selected_pin / 32;
	int set_clr_bit = selected_pin % 32;
	int mem_shift = GPCLR0 + set_clr_sel;
	int mask = 0b1 << (set_clr_bit); // because 0 is one


	//print_32(mem_shift);
	//print_32(mask);
	//print_32(mem_shift);
	*(gpio_mem + mem_shift) = mask;
	return;
}

gpio_drivers::~gpio_drivers()
{
close(fd);
munmap(gpio_mem, 4096);
}

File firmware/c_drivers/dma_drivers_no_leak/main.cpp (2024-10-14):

#include "dma_drivers.h"
//#include <ctime>
#include <unistd.h>
#include "gpio_drivers.h"
#include <iostream>
#include <fstream>
#include <string>

#define SONAR1 16
#define SONAR2 20
#define SONAR3 21

#define MOTOR1_EN 5
#define MOTOR2_EN 6
#define MOTOR3_EN 13
#define MOTOR4_EN 19
#define MOTOR5_EN 26
#define MOTOR6_EN 12

#define L_IN1	8
#define L_IN2	7
#define R_IN1	14
#define R_IN2	15

void move_backward(uint8_t power,dma_handler& dma_object)
{

gpio_drivers::set_high(L_IN1);
gpio_drivers::set_low(L_IN2);
gpio_drivers::set_low(R_IN1);
gpio_drivers::set_high(R_IN2);


dma_object.modify_blocks(power,250,MOTOR1_EN);
dma_object.modify_blocks(power,250,MOTOR2_EN);
dma_object.modify_blocks(power,250,MOTOR3_EN);
dma_object.modify_blocks(power,250,MOTOR4_EN);
dma_object.modify_blocks(power,250,MOTOR5_EN);
dma_object.modify_blocks(power,250,MOTOR6_EN);

}

void move_forward(uint8_t power, dma_handler& dma_object)
{
gpio_drivers::set_low(L_IN1);
gpio_drivers::set_high(L_IN2);
gpio_drivers::set_high(R_IN1);
gpio_drivers::set_low(R_IN2);

dma_object.modify_blocks(power,250,MOTOR1_EN);
dma_object.modify_blocks(power,250,MOTOR2_EN);
dma_object.modify_blocks(power,250,MOTOR3_EN);
dma_object.modify_blocks(power,250,MOTOR4_EN);
dma_object.modify_blocks(power,250,MOTOR5_EN);
dma_object.modify_blocks(power,250,MOTOR6_EN);

}

void turn_left(uint8_t power, dma_handler& dma_object)
{
gpio_drivers::set_high(L_IN1);
gpio_drivers::set_low(L_IN2);
gpio_drivers::set_high(R_IN1);
gpio_drivers::set_low(R_IN2);

dma_object.modify_blocks(power,250,MOTOR1_EN);
dma_object.modify_blocks(power,250,MOTOR2_EN);
dma_object.modify_blocks(power,250,MOTOR3_EN);
dma_object.modify_blocks(power,250,MOTOR4_EN);
dma_object.modify_blocks(power,250,MOTOR5_EN);
dma_object.modify_blocks(power,250,MOTOR6_EN);

}

void turn_right(uint8_t power, dma_handler& dma_object)
{
gpio_drivers::set_low(L_IN1);
gpio_drivers::set_high(L_IN2);
gpio_drivers::set_low(R_IN1);
gpio_drivers::set_high(R_IN2);

dma_object.modify_blocks(power,250,MOTOR1_EN);
dma_object.modify_blocks(power, 250, MOTOR2_EN);
dma_object.modify_blocks(power, 250, MOTOR3_EN);
dma_object.modify_blocks(power, 250, MOTOR4_EN);
dma_object.modify_blocks(power, 250, MOTOR5_EN);
dma_object.modify_blocks(power, 250, MOTOR6_EN);
}

void print_all_thing(dma_handler& dma_object)
{
	std::cout << "\n";

	for (int i=0;i<20;i++)
	{
		std::cout << " " << dma_object.reserved[i].reserved_me;
	}

}

void read_sonar_1(long long& time)
{
	FILE *file;
	file = fopen("/sys/kernel/sonar_1_time/time_diff", "r");
	if (file == NULL) 
	{
    		perror("Error opening file");
		time = -1;
    		return;
	}
	if (fscanf(file, "%lld", &time) != 1) {
    		printf("Error reading number from file\n");
		time = -1;
	} 
	else 
	{
		printf("sonar 1 pre-conversion: %lld\n" , time);
		time = time/58000;
    		printf("sonar_1 Read number: %lld\n", time);
	}
	fclose(file);
}

void read_sonar_2(long long& time)
{
        FILE *file;
        file = fopen("/sys/kernel/sonar_2_time/time_diff", "r");
        if (file == NULL)
        {
                perror("Error opening file");
                time = -1;
                return;
        }
        if (fscanf(file, "%lld", &time) != 1) {
                printf("Error reading number from file\n");
                time = -1;
        }
        else
        {
		time = time/58000;
                printf("sonar_2 Read number: %lld\n", time);
        }
        fclose(file);
}

void read_sonar_3(long long& time)
{
        FILE *file;
        file = fopen("/sys/kernel/sonar_3_time/time_diff", "r");
        if (file == NULL)
        {
                perror("Error opening file");
                time = -1;
                return;
        }
        if (fscanf(file, "%lld", &time) != 1) {
                printf("Error reading number from file\n");
                time = -1;
        }
        else
        {
		time = time/58000;
                printf("sonar_3 Read number: %lld\n", time);
        }
        fclose(file);
}

void prompt_sonar()
{
	gpio_drivers::set_high(SONAR1);
	sleep(0.01);
	gpio_drivers::set_low(SONAR1);
	sleep(0.80);
	gpio_drivers::set_high(SONAR2);
	sleep(0.01);
	gpio_drivers::set_low(SONAR2);
	sleep(0.80);
	gpio_drivers::set_high(SONAR3);
	sleep(0.01);
	gpio_drivers::set_low(SONAR3);
	sleep(.2);
	return;
}


int main()
{

//pwm_dma(125,250,0); // pwm_dma(uint8_t on_block,uint8_t num_blocks_f,uint32_t dma_num)//rate should be a number between>
gpio_drivers::set_output(MOTOR1_EN);
gpio_drivers::set_output(MOTOR2_EN);
gpio_drivers::set_output(MOTOR3_EN);
gpio_drivers::set_output(MOTOR4_EN);
gpio_drivers::set_output(MOTOR5_EN);
gpio_drivers::set_output(MOTOR6_EN);

gpio_drivers::set_output(L_IN1);
gpio_drivers::set_output(L_IN2);
gpio_drivers::set_output(R_IN1);
gpio_drivers::set_output(R_IN2);

//setting up sonar triggers
gpio_drivers::set_output(SONAR1);
gpio_drivers::set_output(SONAR2);
gpio_drivers::set_output(SONAR3);
//end of setting up sonar triggers



dma_handler dma_object = dma_handler(125,250,0,26);
dma_object.turn_off();
move_forward(40,dma_object);

prompt_sonar();


long long sonar_1_value = -1;
long long sonar_2_value = -1;
long long sonar_3_value = -1;


while(1)
{

prompt_sonar();
read_sonar_1(sonar_1_value);
prompt_sonar();
read_sonar_1(sonar_1_value);
sonar_1_value = 0;
move_forward(40,dma_object);

while((sonar_1_value <= 0 || sonar_1_value >= 40)) //&& (sonar_2_value <= 0 || sonar_2_value >= 25) && (sonar_3_value <= 0 || sonar_3_value >= 25))
//while(1)
{
prompt_sonar();
read_sonar_1(sonar_1_value);
//read_sonar_2(sonar_2_value);
//read_sonar_3(sonar_3_value);
sleep(.5);
}

std::cout << "We are running this";
dma_object.turn_off();
sleep(1);
turn_right(100,dma_object);
sleep(2);
dma_object.turn_off();
}





return 0;
}

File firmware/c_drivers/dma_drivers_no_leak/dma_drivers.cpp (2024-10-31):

#define gpiomem "/dev/gpiomem"
#define gen_mem "/dev/mem"
#define GPIOSET0 0x1c/4
#define GPCLR0 0x28/4
#define DMA_OFFSET 0xfe007000

#include "gpio_drivers.h"
#include <cstdint>
#include <sys/mman.h>
#include <fcntl.h>
#include <sys/types.h>
#include <sys/stat.h>
#include <unistd.h>
#include <cstring>

#include <iostream>
#include <bitset>   // Include this for std::bitset
#include "dma_drivers.h"
//#include "dma_mem.h"
#include <fstream>


/*

Control Blocks (CB) are 8 words (256 bits) in length and must start at a 256-bit aligned address.

*/

/*
uint32_t block_one[] = 
{
0x03E00008, //0 TI - flags  0x03E00000
0x00000000, //1 SOURCE AD This is dynamically allocated, let the compiler handle it, will assign to buff>
0x7e20001c, //2 DEST AD  This is a constant as it is legacy addressed - should be GPIOSET0
0x00000004, //3 TXFR_LEM Only ever want to transfer 32 bits
0x00000000, //4 N/A
0x00000000, //5 NEXTCONBK
0x00000000, //6 reserved
0x00000000 //7 reserved
};*/


/*void dma_handler::output_active_gpio(uint32_t first_set, uint32_t second_set)
{
std::ofstream outfile("gpio_toggle_state");
outfile << first_set;
outfile << "\n";
outfile << second_set;
return;
}

void dma_handler::check_active_gpio(uint32_t* two_buffer)
{
std::ifstream infile("gpio_toggle_state");
infile >> *(two_buffer);
infile >> *(two_buffer + 1);
return;
}
*/

void dma_handler::init_data()
{

uint32_t all_on[32] = {};
for (int i = 0; i < 32; i++)
{
        all_on[i] = 1<<i;
}
this->source_info = dma_malloc(sizeof(all_on));
uint32_t* all_on_pointer = reinterpret_cast<uint32_t*>(source_info->virtual_addr);
for (int i = 0; i<32; i++)
{
        *(all_on_pointer+i) = all_on[i];
        //std::cout << "\nArray element : "<<all_on[i] << "\n";
}



for (int j = 0; j<20; j++)
{
        reserved[j].reserved_me = false;
        reserved[j].pin = 40;
}

}

dma_handler::dma_handler(uint8_t on_block,uint8_t num_blocks_f,uint32_t dma_num,uint32_t pin_number)
{

std::cout << "This is runnning";
init_data();
pwm_dma(on_block,num_blocks_f,dma_num,pin_number);

}

void dma_handler::turn_off()
{
        iteration++;
        //std::cout << "iteration number is: " << iteration;
        uint32_t* point_virt = reinterpret_cast<uint32_t*>(dma_cbs->virtual_addr);
        for (int i =0; i<num_control_blocks; i++)
        {
//              std::cout << "\naccessing the element: " << i;
                point_virt[i*8 + 1] = bus_address_off; //fires nothing at all
        }
	gpio_drivers gpio = gpio_drivers();
        gpio.set_low(5);
        gpio.set_low(6);
        gpio.set_low(13);
        gpio.set_low(19);
        gpio.set_low(26);
        gpio.set_low(12);
        for (int i = 0; i<20 ; i++)
        {
//              std::cout << "\naccessing the element " << i;
                reserved[i].reserved_me = false;
                reserved[i].pin = 40;
        }
        num_reserved = 0;
//      std::cout << "\nfinished turning off\n";
}

uint32_t dma_handler::find_index()
{
        uint32_t to_return = -1;
        for (int i = 0; i<20;i++)
        {
                if(reserved[i].reserved_me == false)
                {
                        to_return = i;
                        //std::cout << "\naccepted index = to_return" << to_return;
                        return to_return;
                }
        }
        //std::cout << "\naccepted index = to_return";
        return to_return;
}


void dma_handler::print_all_cbs(uint32_t num_control_blocks,uint32_t* cb_start)
{
for (int i = 0; i<num_control_blocks;i++)
{
        for (int j = 0; j<8; j++)
        {
                std::cout << "\n" <<std::bitset<32>(cb_start[i*8+j]) << "\t" << cb_start[i*8+j];
        }
        std::cout << "\n\n";
}
return;
}

void dma_handler::reset_dma(uint32_t* dma_mem, uint32_t dma_num)
{

*(dma_mem+(dma_num*0x100/4)) = (1 << 31);//may need to do masking stuff here

}


void dma_handler::initiate_dma_transfer(uint32_t* dma_mem ,uint32_t first_cb_address, uint32_t dma_num)
{

*(dma_mem+1+(dma_num*0x100/4)) = first_cb_address;
*(dma_mem+(dma_num*0x100/4)) = 0b1;//may need to do masking stuff here

}

void dma_handler::pwm_dma(uint8_t on_block,uint8_t num_blocks_f,uint32_t dma_num,uint32_t pin_number)//rate should be a number between 50-100 that is % of time on
{

std::cout << "This is running";


if (on_block >= num_blocks_f)
{
        std::cout << "This is not a valid rate number, please provide a value between 0-100; no code exectued" << "\n";
        return;
}

//memory mapping dma memory:
//int dma_num = 0;

char file_name[] = gen_mem;
int flags = 0x101002;
int fd = openat(0,file_name,flags);
std::cout << fd;

uint32_t* dma_mem = reinterpret_cast<uint32_t*>(mmap(0,4096,3,1,fd,DMA_OFFSET));
//end of memory mapping

reset_dma(dma_mem,0);


num_control_blocks = num_blocks_f;


//uint32_t all_on = (1<<pin_number);//0b00001001001001001001001001001001;
uint32_t all_off = 0x0;//0;

//below is virtual mailbox setup to get persistant contigous memory setup
//DMAMemHandle *dma_cbs = dma_malloc(sizeof(block_one)*num_control_blocks);
//DMAMemHandle *source_info = dma_malloc(sizeof(all_on));
//DMAMemHandle *source_info2 = dma_malloc(sizeof(all_off));

this->dma_cbs = dma_malloc(sizeof(block_one)*num_control_blocks);
//this->source_info = dma_malloc(sizeof(all_on));
this->source_info2 = dma_malloc(sizeof(all_off));

//uint32_t* all_on_pointer = reinterpret_cast<uint32_t*>(source_info->virtual_addr);
// /**/(all_on_pointer) = all_on;

uint32_t* all_off_pointer = reinterpret_cast<uint32_t*>(source_info2->virtual_addr);
*(all_off_pointer) = all_off;

uint32_t all_address_base = reinterpret_cast<uint32_t>(source_info->bus_addr);
uint32_t bus_address_on = (uint32_t)((all_address_base+pin_number*4));


bus_address_off = (uint32_t)source_info2->bus_addr;
//second block [1] = bus_address_off  --- done in a lower line



num_reserved++;//We are going to take up two blocks
reserved[0].reserved_me = true;
reserved[0].pin = pin_number;
reserved[0].start = 0;
reserved[0].end = on_block;
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

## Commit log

2024-02-20 First parts of frame
    [Frame_A.SLDPRT, Frame_B.SLDPRT]
2024-02-22 Created assem of old rover, file reorg
    [0_5_in_shaft.SLDPRT, 0_75_in_shaft.SLDPRT, Frame_A.SLDPRT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]
2024-02-22 Added outer wheels
    [Old_Assembly.SLDASM, Wheel.SLDPRT, Wheel_Bracket.SLDPRT]
2024-02-22 Added middle wheels to assem
    [Old_Assembly.SLDASM]
2024-02-22 Created CAD for selected DC motor
    [DC Motor.SLDPRT, Old_Assembly.SLDASM]
2024-02-22 Updated color of frame parts
    [Frame_A.SLDPRT, Frame_B.SLDPRT, Frame_C.SLDPRT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]
2024-02-23 File reorg
    [0_5_in_shaft.SLDPRT, 0_75_in_shaft.SLDPRT, DC Motor.SLDPRT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]
2024-02-23 Fixed axle constraints
    [Old_Assembly.SLDASM]
2024-02-23 Created acrylic chassis
    [Chassis.SLDPRT, Old_Assembly.SLDASM]
2024-02-23 Added pins to swerve joints and created img folder
    [3_in_pin.SLDPRT, Old_Assembly.SLDASM]
2024-02-23 Create README for pcb
2024-03-21 Updated CAD
    [DC Motor.SLDPRT, Frame_Join_A.SLDPRT, Frame_Join_B.SLDPRT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]
2024-03-21 Added new wheel joints
    [0_5_in_shaft.SLDPRT, 0_75_in_shaft.SLDPRT, 3_in_pin.SLDPRT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]
2024-03-22 Added wheel joints to all wheels
    [Fixed_Assembly.SLDASM]
2024-03-22 Assembly cleanup
    [Fixed_Assembly.SLDASM]
2024-03-26 Add BOM Link
2024-03-29 added assembly environment + start DMA
2024-03-29 modif assembly, motor drivers 99% finished
2024-04-13 drivers for temp_motors
2024-04-21 working motors and ISM
2024-04-21 Working sensors
2024-08-30 added camera
2024-09-01 Updated nodes for object detection and motor control
2024-09-08 sensors should look better now :)
2024-09-13 Updating sensor GUI
    [pyvenv.cfg]
2024-09-14 Updating motors gui
    [pyvenv.cfg]
2024-09-14 Updating camera python
2024-09-14 Sensor with Camera UI integration
2024-09-23 controller logs!
    [button_dump.txt, controller_dump.txt]
2024-09-30 Create MotorDriver
2024-10-05 kernel now prints to a file
2024-10-06 sonar kernel modules
2024-10-06 sonar kernels built
2024-10-06 Integrating object detection with sensors.cpp
2024-10-07 testing dma with sonar
2024-10-07 sonar interrupt better
2024-10-07 fixed dma memory leak
    [dma_drivers.cpp, main2.cpp]
2024-10-08 more dma stuff
2024-10-11 before beta
    [controller_dump.txt]
2024-11-01 more sonar stuff
2024-11-13 should be no more bugs in controller script, tried to clean up a bit
    [main_both.cpp]
2024-12-03 Version 4 of PCB that needs thicker traces
    [Driver.PrjPcb, MotorBoard.PcbDoc, MotorBoard.SchDoc]
